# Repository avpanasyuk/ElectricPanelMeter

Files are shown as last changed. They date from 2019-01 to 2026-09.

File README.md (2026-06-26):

# ElectricPanelMeter

A whole-panel electric power meter: custom measurement hardware plus ESP8266
firmware that reports voltage / current / power over the LAN and logs it, with
MATLAB and Python tooling for readout and analysis.

## Layout

- **Hardware** — `Altium/` (PCB), `CAD/`, `Drawings/`, `LTspace/` (LTspice
  schematics) for the measurement boards.
- **`FirmwareV2/`** — current [PlatformIO](https://platformio.org) ESP8266
  firmware (`board = nodemcu`, 4 MB flash, LittleFS). One source builds two
  variants for the main and sub units:
  - `pio run -e main` → device `EPM_main` (`-DVERSION=1`)
  - `pio run -e sub`  → device `EPM_sub`  (`-DVERSION=2`)
  It vendors the shared `C_General` / `C_ESP` / `C_ARDUINO` submodules and uses
  `avp::StaticWebServer` (web UI / config / OTA) plus `avp::RemoteLog`, which
  POSTs `<filename>,<csv>` rows to the home server's `http_server.py` log sink.
  See `FirmwareV2/CLAUDE.md` for build and agent notes.
- **`Firmware/`** — the original (V1) firmware, kept for reference.
- **`MATLAB/`** — analysis code; vendors `github.com/avpanasyuk/MATLAB` at
  `MATLAB/AVP_LIB`. Logging is push-based: since firmware v4.00 the device POSTs
  its CSV rows straight to the home server's `http_server.py`, so no host-side
  polling script is needed.
- **`conf_*.m`, `*.csv`, `*.xls`** — configuration and recorded data.

## Building the firmware

```
cd FirmwareV2
pio run -e main        # main unit  (EPM_main)
pio run -e sub         # sub unit   (EPM_sub)
pio run -e <env> -t upload
```

The firmware libraries are git submodules — clone the repo with `--recursive`
(or run `git submodule update --init --recursive` after a plain clone).

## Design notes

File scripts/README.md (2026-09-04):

# scripts

Data-repair and maintenance drivers for the panel-meter logs on bsd. Run them there
(`python3`), or pipe them over ssh; they take absolute paths and touch nothing else.

⛔ **Every script here computes watts the way `read_file.m` does, and that changed on
2026-09-04**: the GND column is the additive offset common to all channels, so it is
subtracted SIGNED and the magnitude is taken last — never `max(|col| - |gnd|, 0)` per
row, which is the wrong sign on a reversed-CT channel (`Subpanel Red`, `Main Black`,
`26`) and understates it by `2*gnd`. Keep any new script consistent with `read_file.m`.
Slopes and shares are invariant under the change; levels are not.

| script | what it does |
|---|---|
| `diurnal_modulation.py` | Which main-unit channels carry real load, by MODULATION rather than level. A residual offset is constant, so it cannot make a diurnal shape: a channel's hour-of-day swing against the GND column's own separates load from offset below ~25 W, where the level says nothing. >~10x the reference = load. Recompute the yardstick per month. |
| `gnd_sign_correction.py` | How much every past main-board figure moves under the signed-GND fix, month by month, for a consumer that has to correct published numbers rather than re-derive them. Output is committed as `data/gnd_sign_correction_by_month.csv`. Reads the whole archive; ~10 min on bsd. |
| `merge_split_months.py` | Rebuilds one file per month for a `PowerMonitor.*.csv` that arrived split. Dry run by default, `--apply` to change anything. Concatenates in time order (the pieces do not overlap), refuses on a row-count mismatch or a non-increasing join boundary, and moves the sources to `/POOL/ARCHIVE/ESP_LOGS_PRE_MERGE/` rather than deleting them. |
| `channel_health.py` | Per-channel median / p95 / mean watts and duty for the main unit over one or more merged months (`python3 channel_health.py 02 04 08`), using `read_file.m`'s formula. For telling a dead CT from an off breaker: a breaker comes back across months, a fallen CT does not. |
| `gnd_daily.py` | Daily medians for every main-unit channel over the months given, plus each channel's hi/lo contrast and correlation against `Grounding strip`'s high days. Written to find which circuit switches with the intermittent ground current; the answer so far is none of the metered ones. |
| `port10_history.py` | Monthly medians for selected main-unit channels across every month in the archive, plus the raw covariance value beside the GND reference. Dates when a channel changed state, which is what separates a CT that came off from one that never read right. |
| `port9_divider.py` | Regresses port 9 (the GEC CT) on the service-neutral unbalance `|Main Red - Main Black|` per file. The SLOPE is the share of neutral current diverted onto the water main, and it is calibration-proof (numerator and denominator share the board coefficient), so it is comparable across firmware epochs. A rising share is the service-neutral degradation signal; a collapsed r means the CT has moved off the conductor. |
| `port9_paired.py` | The same share by BOTH estimators -- level regression and paired differences of 1-minute means. Prefer the difference slope. Two channels that both follow the daily household rhythm correlate through that common mode whether or not they are physically coupled, so the level regression is only trustworthy when the two agree; where they diverge, the coupling is weak and the level figure is the artefact. |

`merge_split_months.py` was written for the 2026-06/07/08 split, which came from
`http_server.py` rotating past 10 MiB into a single `.1` that it overwrote. That is
fixed at the sink — a filename carrying the month is now exempt from rotation — so this
should not be needed again. Kept because it records exactly how those three months were
reconstructed, and because it is the tool if a month ever splits again: edit `NAMES`.

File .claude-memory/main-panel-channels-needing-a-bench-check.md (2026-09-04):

---
name: main-panel-channels-needing-a-bench-check
description: "Port 9 is the x570 branch circuit (earth path before 2024-10), not the grounding strip; the GEC question is closed as topology; channel labels here are hypotheses, and a level under ~25 W is offset while its modulation is still real"
metadata:
  node_type: memory
  type: project
---

Measured 2026-09-04 with `scripts/channel_health.py` and `scripts/gnd_daily.py`
(main unit, `read_file.m`'s formula).

## Port 9 — the x570 branch circuit, and the GEC question it used to be

`conf_main_v0.m` labels port 9 `x570 branch (earth path before 2024-10)`. The label is
era-explicit because the conf is applied retroactively to all v0 main data and the CT has
been on more than one thing.

### What it is now

The branch circuit feeding the **x570 workstation**, on the **black leg**. Proven twice:
HOUSE_POWER caught x570's smart plug stepping 78 → 811 W and got
`port9 = 1.037 × plug_raw + 4.2 W`, residual sd 40 W, edge simultaneous to the minute —
the ~4 W intercept says that circuit carries x570 and essentially nothing else. Confirmed
here with no plug in the chain: over 2026-08/09 the 350 minutes where port 9 steps >3σ
land in `Main Black` alone (`Main Red` 0.032, `Subpanel Black` 0.007, `Subpanel Red`
0.031, `26` 0.000; r = 0.91 on black). **A CT on an earth path cannot do that** — it
appears as a fraction of the neutral *unbalance*, never 1:1 into one leg.

### Which era is which — the shape test

Correlation of the 1-minute difference in port 9 with each feeder, over **all** minutes,
no selection. ⛔ Slopes are useless inside this span: port 9 sits in the ground-subtraction
residual for most of it, so its steps are near-noise and slope estimates blow up past 100.
Correlation is scale-free and survives that. ⚠ `sub_r` and `sub_b` mirror `red` and
`black` exactly, an artefact of signing each channel by its own long-run mean — compare
r_red against r_black as magnitudes.

⛔ **First check whether the channel is the reference.** `r(Δp9, Δgnd)` in raw signed
counts — no sign convention involved — is ≈0 for every month 2018-12…2024-09, then
**0.890, 0.931, and 0.984–0.996 for 2024-10 through 2025-06**. In that window port 9 *is*
the GND column: the CT reads nothing, `p9 − gnd` is ~0, and any statistic built on it
correlates with every channel through the shared `gnd` term rather than through load.
It carries signal again from 2025-12 (r back to −0.25…−0.65).

| era | raw p9−gnd median | r(Δp9,Δgnd) | r_red | r_black | reading |
|---|---|---|---|---|---|
| 2019-06/07 | −1124 | 0.00 | 0.720 | 0.242 | earth path |
| 2022-06/07 | −866 | 0.01 | 0.807 | 0.359 | earth path |
| 2024-03/04 | −4412 | 0.02 | 0.505 | 0.496 | earth path |
| 2024-08/09 | **+8068** | 0.06 | 0.296 | 0.107 | earth path |
| 2024-10/11 | −60 | **0.89–0.93** | 0.211 | 0.694 | ⛔ no signal — inadmissible |
| 2024-12…2025-06 | ~+150 | **0.98–0.996** | — | — | ⛔ no signal — inadmissible |
| 2026-02/03 | +252 | −0.27 | 0.075 | 0.239 | one leg |
| 2026-08/09 | +1370 | −0.04 | 0.012 | 0.277 | one leg |

⚠ **The `r_black` = 0.694 at 2024-10/11 is that artefact, not a branch signature** —
"black high, red low" is the default for any channel sitting at the reference, because
`Main Black`'s CT is reversed so its watts carry `+gnd` just as a below-reference port 9
does, while red-signed channels carry `−gnd`. HOUSE_POWER caught this; its cleaner
statistic is `asym = pr_black + pr_sblack` (gnd-partialled), which cancels common mode
because those two reversed CTs mirror each other exactly, and which puts 2024-10/11 at
+0.002 — indistinguishable from 44 months of earth path.

**Two CT events. The first is dated; the second is bounded, not dated:**

1. **June–July 2024**, his panel work (240 V garage circuit, another outlet, "maybe moved
   ground wire CT"): the raw sign flips −4412 → +8068 and the magnitude nearly doubles,
   but the shape stays earth-path. **Reversed or repositioned on the earth path**, not
   moved to a load. The coupling changed, which is why the diverted share is only
   consistent up to 2024-04.
2. **The move onto the branch: bounded to 2024-10 … 2025-12, best guess 2024-10.** What
   is certain is a real discontinuity at 2024-09 → 2024-10 — the raw count collapses from
   +7664 to −60 — which needs a physical cause, and no other discontinuity falls between
   there and the channel carrying signal again in 2025-12. That is parsimony, not
   measurement: from 2024-10 to 2025-06 port 9 is the reference and reads nothing, the
   board is dark 2025-07…2025-11, and **a branch circuit with nothing running is
   indistinguishable from a CT clipped to nothing at all**. HOUSE_POWER's `asym` first
   shows the one-leg signature in 2026-01, but that dates the first observed LOAD, not the
   CT move, so it excludes nothing earlier. ⚠ No data gap and no repo trace at 2024-09/10
   — the board was not powered down, so this move left none of the tells the first one
   did. What he did in the panel that autumn is the one open question on this channel.

⛔ **2026-08 is not a CT event** — do not read it as a re-seat or an onset. It is x570
starting to run: `asym` quadruples there while the channel had already been showing a
steady one-leg asymmetry since 2026-01. ⚠ The identity as x570 specifically is anchored
only at the 2026-08/09 end.

⭐ **Corroboration for the modulation rule from a second direction**: through 2026-01…04
the channel sits at 240–322 counts (12–17 W), squarely "pure residual" by level — yet its
`asym` holds a consistent −0.07. Something small and real was on that circuit months
before x570 came back. The ~25 W threshold governs the LEVEL only; the modulation carries
usable signature well below it, exactly as the hour-of-day swing test says.

### Gain

**Port 9 reads ~1.07 × Main Black, bracket [0.97, 1.18]** — ~1.08 absolute against the
feeders' ~1.01. HOUSE_POWER's plug-derived ×1.12 sits inside it; so does 1.00, so
**per-port gains differing by ~10 % on one board is supported, not established**. The
width is this method's, not theirs: their number is a difference of means across a
controlled 733 W step (±3 %), and its uncertainty lives in the plug's unchecked current
leg.

⛔ **Quote the bracket, never a point.** Selecting minutes on |Δport9| inflates its
variance with its own noise and attenuates the forward slope to 0.846 — which reads as
"port 9 is low" and is an artefact. Selecting on |Δblack| instead picks mostly other loads
on that leg (r = 0.107). Use `[slope(y|x), 1/slope(x|y)]`, both from the port-9-selected
set.

### The GEC finding — CLOSED, do not reopen

⛔ **Do not ask him to move the CT back.** He decided on 2026-09-04 that it stays and that
no alarm is built on the diverted share. The conductor port 9 used to watch is the panel's
**grounding electrode conductor to the water main**, clamp-measured at **3.2–3.3 A**:
parallel-path objectionable current (NEC 250.6), because the metal water service is a
bonded electrode and the utility neutral is multi-grounded, so neutral return divides
between the service neutral and the water main. A copper water main is not much worse a
conductor than an aluminium service neutral, and the divider ratio implies
`Z_gec ≈ 2.7 × Z_neutral`. It is topology, which is why nothing ever tripped on it in six
years — and the parallel path *lowers* effective neutral impedance (`Z_eff = 0.73 × Z_n`)
rather than raising it, so there is no degradation signal being lost.

⛔ **Never open the GEC/water bond while it carries current** — arcing, loss of the ground
reference, and if the utility neutral is compromised the pipe may carry the
neighbourhood's return, so breaking it can energise the plumbing. A "remove the bond
jumper" test applies to a *load-side* bond only, never here. The one safe decisive test if
it is ever reopened: open the main disconnect and re-clamp the GEC — gone means his own
load (look for a load-side N-G bond, 250.142(B)); still there means utility/neighbour
return, and a POCO matter.

**The diverted share** — port 9 regressed on the service-neutral unbalance
`|Main Red − Main Black|`, `scripts/port9_divider.py` — was flat at **0.285–0.298 across
2019–2023**, and the series ends at **2024-04**. ⚠ One residual, recorded and not pursued:
it rose to 0.326 [0.322, 0.330] in 2024-03 and 0.329 [0.326, 0.332] in 2024-04 —
non-overlapping CIs — *before* the panel work, so his answer does not account for it.

⛔ **Use the PAIRED-DIFFERENCE slope, never the level regression** (`port9_paired.py`).
Port 9 and the unbalance both follow the daily household rhythm, so they correlate through
that common mode whether or not they are physically coupled — the level estimator read
0.43 where the truth was 0.045. The two agree to a few percent when a CT is on the
conductor and diverge 6–10× when it is not, and that divergence is itself the diagnostic:

| month | level slope | diff slope |
|---|---|---|
| 2022-06 | 0.315 | 0.319 |
| 2024-04 | 0.350 | 0.336 |
| 2024-08 | 0.064 | 0.063 |
| 2026-01 | 0.001 | −0.001 |
| 2026-08 | 0.204 | 0.034 |
| 2026-09 | 0.431 | 0.045 |

### Instrument facts established while chasing this

- **Crosstalk and a load-dependent GND reference are both ruled out.** Against 106
  compressor steps >50 W the feeders respond at slope 0.31–0.35 as they must, while port 9
  gives 0.0037 (r = 0.023); and 1834 feeder steps >200 W move the GND reference at slope
  −0.005 (r = −0.078). Low-power channels carry no load-scaling floor.
- ⚠ **Citation hygiene.** NEC **250.6** (*Objectionable Current*) and **250.142(B)**
  (*Load-Side Equipment*) were confirmed independently. The IAEI "parallel paths" article
  does not resolve here, so its "large percentage of the neutral current" quote is
  **unverified**; NEC section *text* was only ever seen via a third-party scrape of
  NFPA-copyright material, which is no authority. Verified sources: Mike Holt's N-G
  voltage article, EC&M's "What's Wrong Here" (green bonding screw in a load-side
  subpanel).
- ⭐ **One minute with a clamp meter beat eight years of logs**, and one question to him
  then dated the CT move. The archive cannot separate a real current from a mislabelled
  CT. Reach for the instrument and for the owner before the regression.

**HOUSE_POWER owns the electrical question; this project owns the meter.**

## ⛔ "Exactly 0.0 W" means FLOORED, not disconnected — in any figure predating 2026-09-04

`read_file.m` used to compute `max(|col| - |gnd|, 0)`, so any channel whose raw value
sat below the GND reference reported a flat zero. In 2024-10 **four** main channels read
0.0 every day — A/C compressor, Grounding strip, 28 Air handler, 40 Lida — and the
A/C one is simply "October, no cooling". A zero therefore means *below the noise
reference*, and only a **step in the raw value against a stable reference** says
something physically changed. Read the raw columns before calling a channel dead.

The clamp is **gone** as of the signed-subtraction fix, so such a channel no longer reads
0.0 — it reads the magnitude of its residual against GND, which is an artefact of order
±20 W and not power. Same rule, different symptom: read the raw columns.
See [[read-file-ground-subtraction-sign]].

## ⛔ `conf_main_v0.m` channel LABELS are not reliable

Port 10 is labelled `28 Air handler attic`. The attic air handler runs
continuously and a blower is hundreds of watts, but the channel read **3–20 W from
2018-12 to 2024-09** and then **exactly 0.0 from 2024-10 on** (raw stepped ~360 →
201 against a ~308 GND reference; it now sits below the reference, which floored the
watts at zero under the old estimator). ⭐ **It is dead, confirmed by modulation**: its
hour-of-day swing is 1.3× the GND column's own, i.e. it tracks the reference and carries
no load at all. That also rules out reading its +6.7 W since 2025-12 as an A/C response.

His reading: **3–20 W is far too low for that air handler, so the channel is probably
mislabelled** — it was measuring some other small load, which stopped in 2024-10.

**Consequence: treat every label in `conf_main_v0.m` as a hypothesis, not a fact.** That
is no longer speculative — port 9 spent six years labelled `Grounding strip` while the CT
moved twice, and the label cost this project a long grounding-electrode investigation
before a clamp meter settled it.

Open questions for a panel visit: what port 10's CT is actually clamped on, why it
went dead in 2024-10, and whether the attic air handler is metered at all.

## ⛔ `38 Vova` (port 11) — NOT disturbed by the 2024 work. It swings on its own.

Two sessions asserted a 2024 collapse here and both were wrong, because both read one
high run as a baseline. The full corrected series (monthly means, W, whole archive)
settles it:

| span | port 11 |
|---|---|
| 2018-12 … 2019-08 | 8.5–13.7 |
| 2019-09 … 2020-05 | 18.9 → 34.4, rising |
| 2020-06 … 2021-07 | 36.4–**107.4** |
| 2021-08 | **7.7** — the sharpest step this channel has ever made |
| 2021-10 … 2023-11 | 12–47, variable |
| 2023-12 … 2024-05 | 45.8–64.9 |
| 2024-08 … 2026-01 | 2.0–12.6, except **34.7** in 2025-04 |
| 2026-02, -03, -06 | **38.9, 48.0, 28.2** |

⇒ **There is no discontinuity at the June–July 2024 panel work.** The channel's monthly
mean has ranged 2–107 W for its whole life and returns to 28–48 W repeatedly after 2024.
Its one genuinely sharp, unexplained step is **2021-07 → 2021-08, 107.4 → 7.7 W** — which
nobody has looked at, and which is far larger than anything in 2024.

⚠ **Its low months are not level measurements.** 2–12 W sits inside the ±20 W
per-channel residual, so "port 11 was quiet" and "port 11 read nothing distinguishable
from zero" are the same statement about its LEVEL. The same trap makes channel `24`
appear to step 12 → 26 W at the 2025-12 flash: 270 counts against the GND column's own
250-count step, i.e. the reference, not the circuit — the feeders moved only ×1.105 there.
**Test the modulation instead**: `24` swings 17× the GND column's own diurnal swing and
port 11 19×, so both carry real load regardless of where their levels sit. The rule and
the measured yardstick are in [[read-file-ground-subtraction-sign]].

⇒ The June–July 2024 work disturbed **port 9 only**. `24` and `26` are flat across it
(12 W, and 111–186 W either side), and so, correctly read, is port 11.

## `40 Lida` (port 12) — alive, and the one channel that matches its label

⛔ **The "exactly 0.0 from 2021-10 onward" that this note used to carry was the old
estimator's clamp, not the circuit.** Corrected, port 12 reads a small but unmistakably
real load: 2026-02 mean 11.8 W, median 10.5, p95 24.1. Its level sits inside the ±20 W
residual, so the level alone says nothing — but its **hour-of-day swing is 615.6 counts,
43× the GND column's own**, the largest ratio on the board, running 11.5 → 43.5 W with a
midday peak. That is a daily-use circuit behaving exactly as its door-table label implies,
and it is one of the few main-panel channels that does.

Its level did drop around 2021-09 (15–91 W before), which is real and unexplained, but the
channel was never dead. **Not a fault.**

## ⛔ There is NO constant reference load — do not use `22 heat exchanger`

`22 heat exchanger` looks like the steadiest load in the house (within 2026-02:
p05 109, p95 123 W) and its monthly median moves 122 W (2019-01) → 79 W (2025-05)
→ 119 W (2025-12) → 107 W (2026-08). **That is not instrument drift.** The user
ran it through an **auto-transformer and adjusted it from time to time**, removing
the auto-transformer during 2026. Its level is a record of those adjustments, so it
cannot calibrate anything and a year-over-year change in it is not a finding.

What does stand: the **GND reference channel steps ~300 → ~550** at the 2025-12
firmware rebuild (the `/read` fix; the sampling loop was reworked again in
2026-05). That channel is a grounded mux input, so it carries the additive offset
common to every channel, not a load — and since it is *subtracted* from every
channel, a step in it moves every reading. Not evidence of a gain change, but it is
**epoch-dependent bias**, and it scales the old code's wrong-sign subtraction on a
reversed-CT channel as `2·gnd`: ~85 W per reversed channel before the step, ~140 W
after. `Main Black` is reversed, so pre-fix mains totals are low by that much and the
error nearly doubles across the 2025-12 boundary.
See [[read-file-ground-subtraction-sign]].

**No validated constant load exists in this data**, so gain stability across
firmware epochs is currently unmeasured in either direction. A known resistive load
would settle it, and is the same bench test that settles the two-board question.

## Reading the numbers

Never quote a `max` from this data — at 0.33 % duty an extremum is an aliasing
artefact. Resample on **local** time: a UTC monthly resample relabelled to local
shifts every bucket by a month.

**Feeder arithmetic closes on the main unit, and closes better since the signed-GND fix.**
2026-02 means: Main Red + Black **2401.2 W**, Subpanel Red + Black **2071.5 W**,
difference **329.7 W** against **368.6 W** of metered main branches — of which ~18.6 W is
port 10's pure residual, so ~350 W is real. That is a ~6 % closure, against a 15 % gap
under the old estimator. ⚠ The *difference* is invariant under the fix (each leg pair
contains exactly one reversed CT, so both sides gain the same ~140 W); it is the branch
total that moved.

So the ~40 % gap between the subpanel feed and the sub unit's 14 branches is a sub-side
question — unmetered subpanel circuits, or the two boards' separate calibrations
(`conf.coeff` 385 vs 328.2). A known resistive load read on both units separates them, and
is immune to the PLUG fleet's undocumented 1.08 power trim.

See [[epm-main-unreliable-for-years]].

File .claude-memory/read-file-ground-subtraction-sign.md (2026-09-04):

---
name: read-file-ground-subtraction-sign
description: "read_file.m subtracted the GND reference from the MAGNITUDE, understating every reversed-CT channel (incl. Main Black) by ~140 W; fixed. There is NO 2 kW rectification floor - that was solar."
metadata:
  node_type: memory
  type: project
---

**Retracted: there is no ~2.1 kW rectified floor on the feeders.** The constant
`Main Red + Main Black` that looked like one is **gross consumption** — the PV array is
line-side tapped, so the main-panel CTs sit downstream of it and never see the
production, while the bill reads net. HOUSE_POWER owns that identity
(`gross = net + production`) and the resulting per-epoch gains.

**What is really wrong with the old `read_file.m`, in order of size.** Each CSV value is
`cov(V,I)` over one free-running 60 Hz window (`harvest_scan()` in `main_v2.cpp`), so it
is **signed**; the sign is CT orientation, not direction of flow. The last column is a
grounded mux input — no CT, so it carries only the additive offset every channel picks
up (~505 counts on the main board, Sept 2026).

1. **Wrong-sign ground subtraction — the real defect.** The old code did
   `max(|col| − |gnd|, 0)`. For a channel whose CT is reversed (`Subpanel Red`,
   **`Main Black`**, `26`) that subtracts the offset from the magnitude instead of from
   the signed value, understating it by **2 × gnd ≈ 1012 counts ≈ 140 W**. `Main Black`
   is a feeder, so the mains total was low by ~140 W — **+5.6 % on Sept 2026**
   (2533 → 2675 W).
2. **Rectification of near-zero channels — real but small.** `mean(|x|) ≠ |mean(x)|`
   still holds, but consecutive-sample scatter is only ~85 counts on Main Red and
   ~225 on Main Black = **10–30 W**, nowhere near the ~1000 counts a 2 kW floor needs.
   It only bites a channel sitting at the offset, and there the `max(…,0)` clamp
   dominates anyway.

**Measured across the whole archive** (`scripts/gnd_sign_correction.py` →
`data/gnd_sign_correction_by_month.csv`, 79 months, 2018-12…2026-09): the mains
correction is **+3.2 to +5.0 % in every month through 2025-06**, then **+4.7 to +7.2 %
from 2025-12 on** — the GND channel's ~300 → ~550 count step at that firmware rebuild,
showing up exactly where it must. In watts, ~82 W before and ~150 W after. It is a
per-epoch multiplicative-looking bias that is really a fixed additive one, so it hits a
low-consumption month hardest.

**The GND column is a common additive offset — verified, not assumed.** With its breaker
off, `25 - Main A/C compressor` sits at a median of **517 counts** against the GND
column's own **511**. A switched-off load reading exactly the reference is what makes the
signed subtraction correct.

**Residual floor after the fix: ±20 W per channel, not zero.** `28 Air handler attic` and
`40 Lida` average *below* GND (363 and 191 counts vs 505), so the offset is not identical
across mux inputs, and a level of that size is not by itself a measurement.

⛔ **But test the MODULATION, not the level — a residual is constant, so it cannot make a
diurnal shape.** "Under 25 W means nothing" is too blunt and throws away real load. The
GND column's own hour-of-day swing is the yardstick: **14.2 counts** over 2026-03
(357950 rows). Against it, same month:

| channel | swing | × GND | W range |
|---|---|---|---|
| `40 Lida` | 615.6 | **43×** | 11.5 → 43.5 |
| `38 Vova` | 273.9 | **19×** | 43.4 → 57.6 |
| `24` | 238.7 | **17×** | 13.0 → 25.4 |
| port 9 (x570 branch) | 80.6 | 5.7× | 9.9 → 14.1 |
| `28 Air handler attic` | 18.8 | **1.3×** | −18.9 → −17.0 |

⇒ `40 Lida` and `24` carry real diurnal load of tens of watts even though their LEVELS sit
in the residual band. ⇒ `28 Air handler attic` tracks the reference and does not modulate
at all — which confirms it reads nothing far more strongly than the level argument did,
and rules out the "responds slightly to A/C" reading of its +6.7 W since 2025-12.

**The rule: below ~25 W a branch channel's LEVEL is offset; its MODULATION is real when it
is ≳10× the GND column's own swing in the same month.** Compute the yardstick per month —
it scales with the offset, which stepped at the 2025-12 flash.

⛔ **Before any correlation or shape statistic on a low channel, check `r(Δchannel, Δgnd)`
in RAW SIGNED COUNTS.** A channel whose CT reads nothing does not go quiet — it becomes
the GND column, and then every statistic derived from `channel − gnd` correlates with
every other channel through the shared `gnd` term, with no load anywhere. It looks exactly
like a real coupling. Port 9 hits 0.89–0.996 across 2024-10…2025-06 and manufactured a
convincing "black leg" signature there; ≈0 is the healthy value, and every month
2018-12…2024-09 sits at ≈0. **A high r means the channel is inadmissible, not that it is
coupled to something.** Since a reversed CT's watts carry `+gnd` and a normal one's carry
`−gnd`, the artefact always looks like "the reversed channels respond and the others
anti-respond" — cancel it with a sum over a mirrored pair
(`asym = pr_black + pr_sblack`, gnd-partialled) rather than reading the halves.

**How to apply:** `read_file.m` now subtracts GND signed, applies one fixed per-channel
sign taken from the whole-record mean, and no longer clamps at zero — so reverse flow
survives (a future load-side PV, battery or bidirectional EV charger would be visible;
the present line-side array still is not). Any watt figure published before 2026-09-04
for a reversed-CT channel is ~140 W low. See
[[main-panel-channels-needing-a-bench-check]].

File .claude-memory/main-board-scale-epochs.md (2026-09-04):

---
name: main-board-scale-epochs
description: "Complete record of every date the reported watt scale could have moved - conf edits, firmware, hardware - plus the GND column as the epoch instrument. A conf edit can never make a boundary; the FLASH date does, not the commit."
metadata:
  node_type: memory
  type: project
---

Assembled 2026-09-04 from the repo's own history, for HOUSE_POWER's bill calibration,
which was inferring epochs from the signal. Use this instead of a detector.

⛔ **A `conf.coeff` or port-coefficient edit CANNOT create an epoch boundary.** The
conf is selected by the version digit in the log filename and applied retroactively to
every row read with it, so an edit uniformly rescales that version's whole history — it
never steps the data at the edit date. The only conf-driven boundary is a change of the
*filename version digit* (sub v0→v1→v2), which selects a different file.

⛔ **The commit date is not the boundary — the FLASH date is, per board.** Proof: the
sampling rewrite is 2025-07-03, but main's data steps at 2025-12, because main logged
nothing between 2025-06 and 2025-12 and was reflashed around 2025-12-10. The two boards
do not share boundaries. Bound a flash by the coverage gap.

## Conf edits — complete

- `conf_main_v0.m`: `conf.coeff = 385` never changed since the file was created
  (351866c, 2019-05-11). Port coefficients changed **once**: 2020-01-02 (34e18ec), ports
  6 and 10 `50` → `50/2` "two phases" — a retroactive ×0.5 on `25 - Main A/C compressor`
  and `28 Air handler attic`. 2024-08-13 (5538c31) is **labels only**. The four feeder
  coefficients (18.8) have never moved.
- `conf_sub_v2.m`: `conf.coeff` 376.62 → 328.18 at 2025-07-02 (065f33d) — retroactive
  ×1.148 on all sub-v2 watts. 2026-09-02/03 changed `conf.dir` only.
- `conf_sub_v0.m` / `conf_sub_v1.m`: 376.62, untouched since 2019-05-11.

## Firmware — only three things can move the scale

`LastPower = (Power − Current·Voltage/N)/N` normalizes by sample count, so the sampling
RATE does not change the scale. Only an explicit factor, the mux settling `Delay`, and
the V→I sample phase can.

- `SAMPLES_IN_WF = 600` unchanged since 2018-12-05; `Delay = GetDelay(4)` (160 µs)
  unchanged since 2018-12-09 (`GetDelay(5)` for the four days before).
- **2019-05-10 → 05-11** (a87409d → 1d09284): phase interpolation added, reverted next day.
- **2025-07-02 → 07-03** (065f33d → eda9b90): `NumSamplesPerWL = 8` put an explicit extra
  `/8` on every reported power. Anything logged in that one-day window is **8× low**.
- ⭐ **2025-07-03 (eda9b90)**: rewrote the cadence to `WIFI_timeRatio = 10` — read one
  port flat out, then yield 10 wavelengths to WiFi. Changes the V→I sample spacing, hence
  the phase error, hence the gain. **This is the 2025/2026 boundary**, reaching main only
  at its 2025-12-10 flash.
- **2026-06-08 (c00840b, v5.04)**: fixed a race where `/read` and the bsd push stole each
  other's accumulator, so a value could be a partial scan. **Exclude 2026-05-25…06-08.**
- Everything else 2025-11 → 2026-06 is WiFi/OTA/mDNS/logging/LED, not the ADC path.
- **Nothing between 2024-08-13 and 2025-07-02** — one commit in that whole window, and it
  is the label-only conf edit.

## ⭐ The epoch instrument: the main board's GND column

The last CSV column is a grounded mux input, so it is the additive offset with **no load
in it**. Annual mean ADC counts from `data/gnd_sign_correction_by_month.csv`
(`gnd_counts`): 2019 297.8, 2020 298.4, 2021 295.0, 2022 305.0, 2023 309.0, 2024 306.0,
2025-12 562.8, 2026 528.0. Flat inside ±5 % for seven years, then one clean step, no
drift. **Two epochs on main and nothing else.** It is a board diagnostic, so it is the
check, not the key — but it beats any load channel. See
[[read-file-ground-subtraction-sign]] for why that column matters twice over.

## The 2024-06/07 gap — ANSWERED by him, 2026-09-04

He did the panel work himself: **added a 240 V circuit to the garage, added another
power outlet, and "maybe moved ground wire CT"** — his words, "it should not have
changed anything else." Main is dark through 2024-06/07 because he powered the board
down to work.

That accounts for the GND step (294.8 → 329.3 → 308.2 by 2024-10) and for port 9's CT
being reversed or repositioned on the earth path — the archive could never have supplied
either. ⚠ It does **not** account for port 9 becoming a branch channel: that is a second,
undocumented CT move at 2024-09/10, with no data gap and no repo trace
([[main-panel-channels-needing-a-bench-check]] has the shape test that dates it). **The feeders did not move**:
HOUSE_POWER's bill-plus-PV chain reads ~0.914 either side, so the board's scale is
unchanged. CT and wiring work, not calibration. Treat **2024-06-01 … 2024-08-01 as a
hard discontinuity for port 9 alone** — port 11 was wrongly added to it by both sessions
and does not belong (see [[main-panel-channels-needing-a-bench-check]]).

⛔ **The lesson, worth more than the answer: when a step lands in a window where the
meter also went dark, ASK HIM FIRST.** Those two coincide precisely because he powers the
board down to work on the panel, so the gap is the tell. Two sessions spent a long
exchange inferring a physical event from ADC counts, firmware history and commit logs,
and one question settled it. HOUSE_POWER records the same lesson in its own
`panel-work-june-july-2024.md`.

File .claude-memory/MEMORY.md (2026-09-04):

- [Power log data flow](power-log-data-flow.md) — every reader goes to `//bsd/ARCHIVE/ESP_LOGS`; `/mnt/T` still answers but is frozen at 2026-09-02.
- [ESP log sink rotation truncates months](esp-log-sink-rotation-truncates-months.md) — the 10 MiB rotation overwrote its single `.1` and destroyed most of Jun–Aug 2026; months since rebuilt to one file each; fix deployed on bsd.
- [EPM_main unreliable for years](epm-main-unreliable-for-years.md) — 9–63 % coverage since 2020, and 4.5 months of payload-free rows in 2025 that every liveness check read as green.
- [Main-panel channels needing a bench check](main-panel-channels-needing-a-bench-check.md) — port 9 is x570's branch circuit, not the grounding strip; the GEC's 3.2-3.3 A is closed as topology; labels in `conf_main_v0.m` are hypotheses, and below ~25 W the level is offset while the modulation is still real.
- [read_file ground-subtraction sign](read-file-ground-subtraction-sign.md) — no 2 kW floor (that was line-side solar); the real defect was subtracting GND from the magnitude, ~140 W low on every reversed-CT channel including Main Black. Fixed.
- [Main-board scale epochs](main-board-scale-epochs.md) — every date the watt scale could have moved; a conf edit never makes a boundary, the flash date does, and the GND column is the instrument.

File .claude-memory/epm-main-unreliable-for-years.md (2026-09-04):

---
name: epm-main-unreliable-for-years
description: "EPM_main has logged only 9-63% of wall-clock minutes every year since 2020, including a 4.5-month run of payload-free rows in 2025"
metadata:
  node_type: memory
  type: project
---

Coverage (% of wall-clock minutes actually logged), measured 2026-09-04 by the
HOUSE_POWER session across all 173 sink files:

| year | main | sub | | year | main | sub |
|---|---|---|---|---|---|---|
| 2020 | 62 | 86 | | 2024 | 40 | 80 |
| 2021 | 36 | 59 | | 2025 | **9** | 52 |
| 2022 | 42 | 47 | | 2026 | 59 | 53 |
| 2023 | 63 | 83 | | | | |

The only stretch in eight years where both units were near-complete is
2026-01 … 2026-04. 2026-05 onward reads low for both, but that is
[[esp-log-sink-rotation-truncates-months]], not the devices.

**2025-07-03 → 2025-11-15, EPM_main posted ~975,600 rows containing a timestamp
and one trailing comma — no payload**, at the normal 5 s cadence. It recovered
2025-12-10 15:22:23, mixed with short rows for ~24 minutes around that point.
**Diagnosed and long since fixed.** Commit `4787751` (2025-07-02, "a lot of time
is wasted on String reallocations") made `samples2string()` return a reference to
a static buffer that `/read` passed straight into `send()`; `5e500c6`
(2025-12-10 17:07, "was not formatting /read string properly") fixed it by
assembling into its own buffer. In 2025 the rows came from a host-side poller
reading `/read`, so a malformed response wrote a timestamp and an empty field.
Both boundaries bracket the commits with flash-then-commit ordering (data
recovered 2025-12-10 15:22, commit 17:07). Nothing to look for in current
firmware; treat 2025-07-03 → 2025-11-15 as a known-bad window and exclude it.

**Why it matters beyond the data:** the device was up, on WiFi, posting on
schedule; file mtime, growth rate and rows-per-day were all nominal for 4.5
months. Every liveness check reads green — only parsing the payload catches it.
Treat "posted but empty" as a distinct failure from "did not post".

**How to apply:** don't read a quiet stretch in the main-panel log as a house
event; check the unit first. Before trusting any long-run comparison of main
against sub, check coverage for that window — main's history is thin.

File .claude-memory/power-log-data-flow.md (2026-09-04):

---
name: power-log-data-flow
description: "Where EPM power CSV logs live on bsd, and which dir the MATLAB scripts read"
metadata: 
  node_type: memory
  type: project
  originSessionId: 8b29c43a-0137-4fb7-b923-2893ff129f92
---

The ESP firmware pushes power-meter CSV rows to bsd's `http_server.py` sink,
which writes them into **`/POOL/ARCHIVE/ESP_LOGS`**
(SMB share `//bsd/ARCHIVE/ESP_LOGS`). One directory, live and historical
together: there is no second location and no monthly move job. `MATLAB/show1.m`,
`show.m` and `month_by_month.m` all `cd` there, and `conf_sub_v2.m` sets
`conf.dir` to the same path.

**Why:** the old two-tier flow (live buffer on `/mnt/T` = `//bsd/USB_FLASH`,
month-end move to `/POOL/ARCHIVE/POWER`) was retired in the 2026-09-02 sink move.
`/POOL/ARCHIVE/POWER` no longer exists, and `/mnt/T` is still mounted but frozen
at 2026-09-02 21:11 — it answers reads with pre-move data and **no error**, so
anyone following the old note gets stale rows with no clue anything is wrong.

**How to apply:** every reader → `//bsd/ARCHIVE/ESP_LOGS`. Never `/mnt/T` or
`//bsd/USB_FLASH`. One file per month, no chunks — `ESP_LOGS_PRE_MERGE/` holds
duplicate rows and is deliberately outside the sink dir, so never glob the tree
recursively. Column 1 is dual-format (legacy Unix epoch +
`yyyy-MM-dd HH:mm:ss.SS` since 2026-06-23) and both can appear in one file,
handled by `read_file.m`.
See [[esp-log-sink-rotation-truncates-months]] before trusting a month's row count.

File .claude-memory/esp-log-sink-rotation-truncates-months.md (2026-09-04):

---
name: esp-log-sink-rotation-truncates-months
description: "The 10 MiB rotation that overwrote its single .1 destroyed most of Jun-Aug 2026; fixed in C_ESP and deployed, months rebuilt to one file each"
metadata:
  node_type: memory
  type: project
---

bsd's `http_server.py` rotated a log to `<file>.1` past 10 MiB and **replaced**
any existing `.1`. At the meters' ~104 KB/h it fired every ~4 days, so only the
last two chunks of a month survived. Roughly the 1st ~10:00 to the 23rd–26th of
2026-06, -07 and -08 is gone on both units — unrecoverable (written to `/mnt/T`,
UFS on a USB stick, outside every snapshot).

**Fixed in C_ESP `development` (9fc4625) and running on bsd.** A filename carrying
the month (`--no-rotate-pattern`, `MONTHLY_NAME_RE`) is exempt from size rotation,
so the power logs stay one file per month; other names keep the cap but the
over-size file is renamed to `<file>.<YYYYmmdd-HHMMSS>` and kept. Disk protection
is `--max-rows-per-min` plus a `--dir-quota-bytes` alert, neither of which deletes.
`test_http_server.py` sits beside it — run it after any change there.

Note for future pushes: `~panasyuk/GIT_REPS/LIBS/C/ESP` on bsd is a working clone
with `receive.denyCurrentBranch=updateInstead`, so **pushing C_ESP to `HOME`
updates the file the sink runs**. It takes effect only on the next `http_server`
restart, which drops in-flight POSTs and is the user's call.

**Repaired 2026-09-04:** 42,164 rows recovered from ZFS snapshots (the first
~10 h of each month, from the retired monthly rsync's copies), then each month
merged back to a single file — 115784/95224/98066 rows main, 96512/103779/92124
sub. Pre-merge sources kept at `/POOL/ARCHIVE/ESP_LOGS_PRE_MERGE/`, deliberately
**outside** `ESP_LOGS/` so a reader walking the tree cannot double-count them.
`scripts/merge_split_months.py` is the tool and the record of how.

**Why it stayed invisible:** the sink returned 200 and logged only
"Rotated <file>". Retention is no backstop either — POOL/ARCHIVE's weekly
snapshots have not fired since 2026-08-09, so a rotated chunk lived ~7 days in
the dailies and was then gone.

See [[power-log-data-flow]] and [[epm-main-unreliable-for-years]].

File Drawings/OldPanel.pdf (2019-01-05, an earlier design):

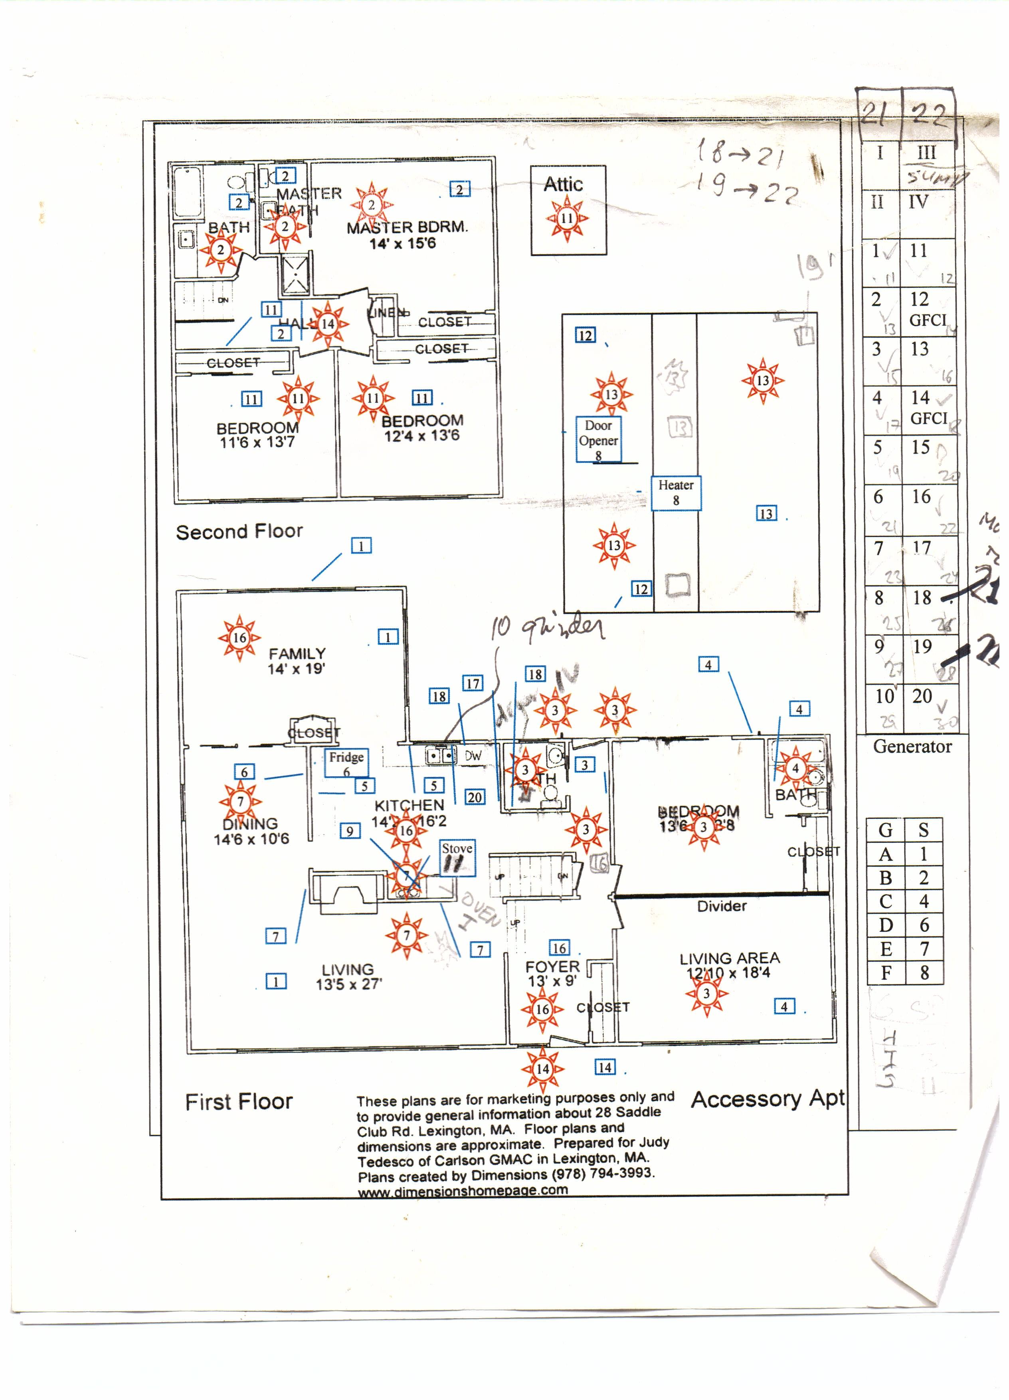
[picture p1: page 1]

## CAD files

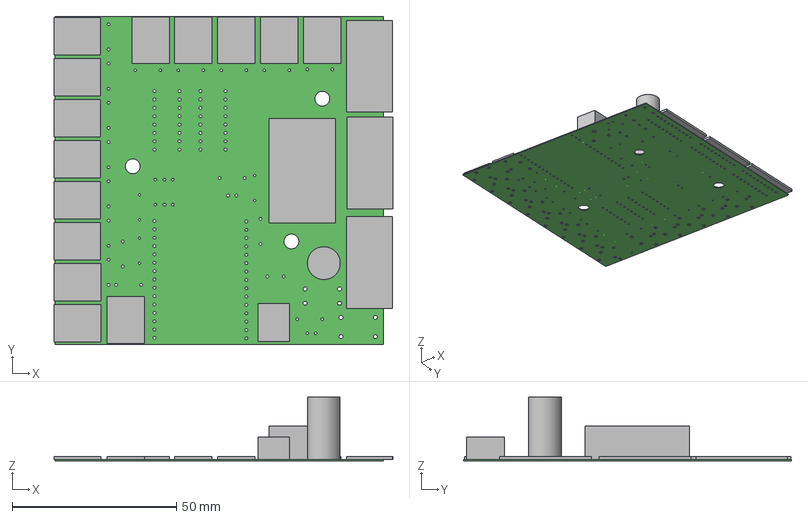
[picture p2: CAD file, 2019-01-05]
Altium/PCB1a.step
103.1 x 99.8 x 19.4 mm
Board
Extruded x 19

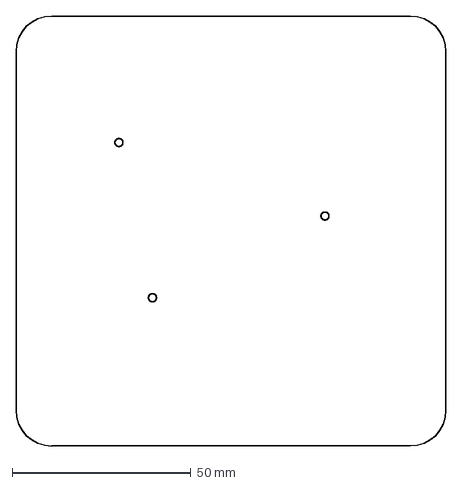
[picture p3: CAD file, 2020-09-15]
CAD/Part2.DXF
120.3 x 120.3 mm

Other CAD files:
CAD/Part1.STEP
Altium/PCB1a.DWG
Altium/PCB1a.DXF
CAD/Part1.DXF

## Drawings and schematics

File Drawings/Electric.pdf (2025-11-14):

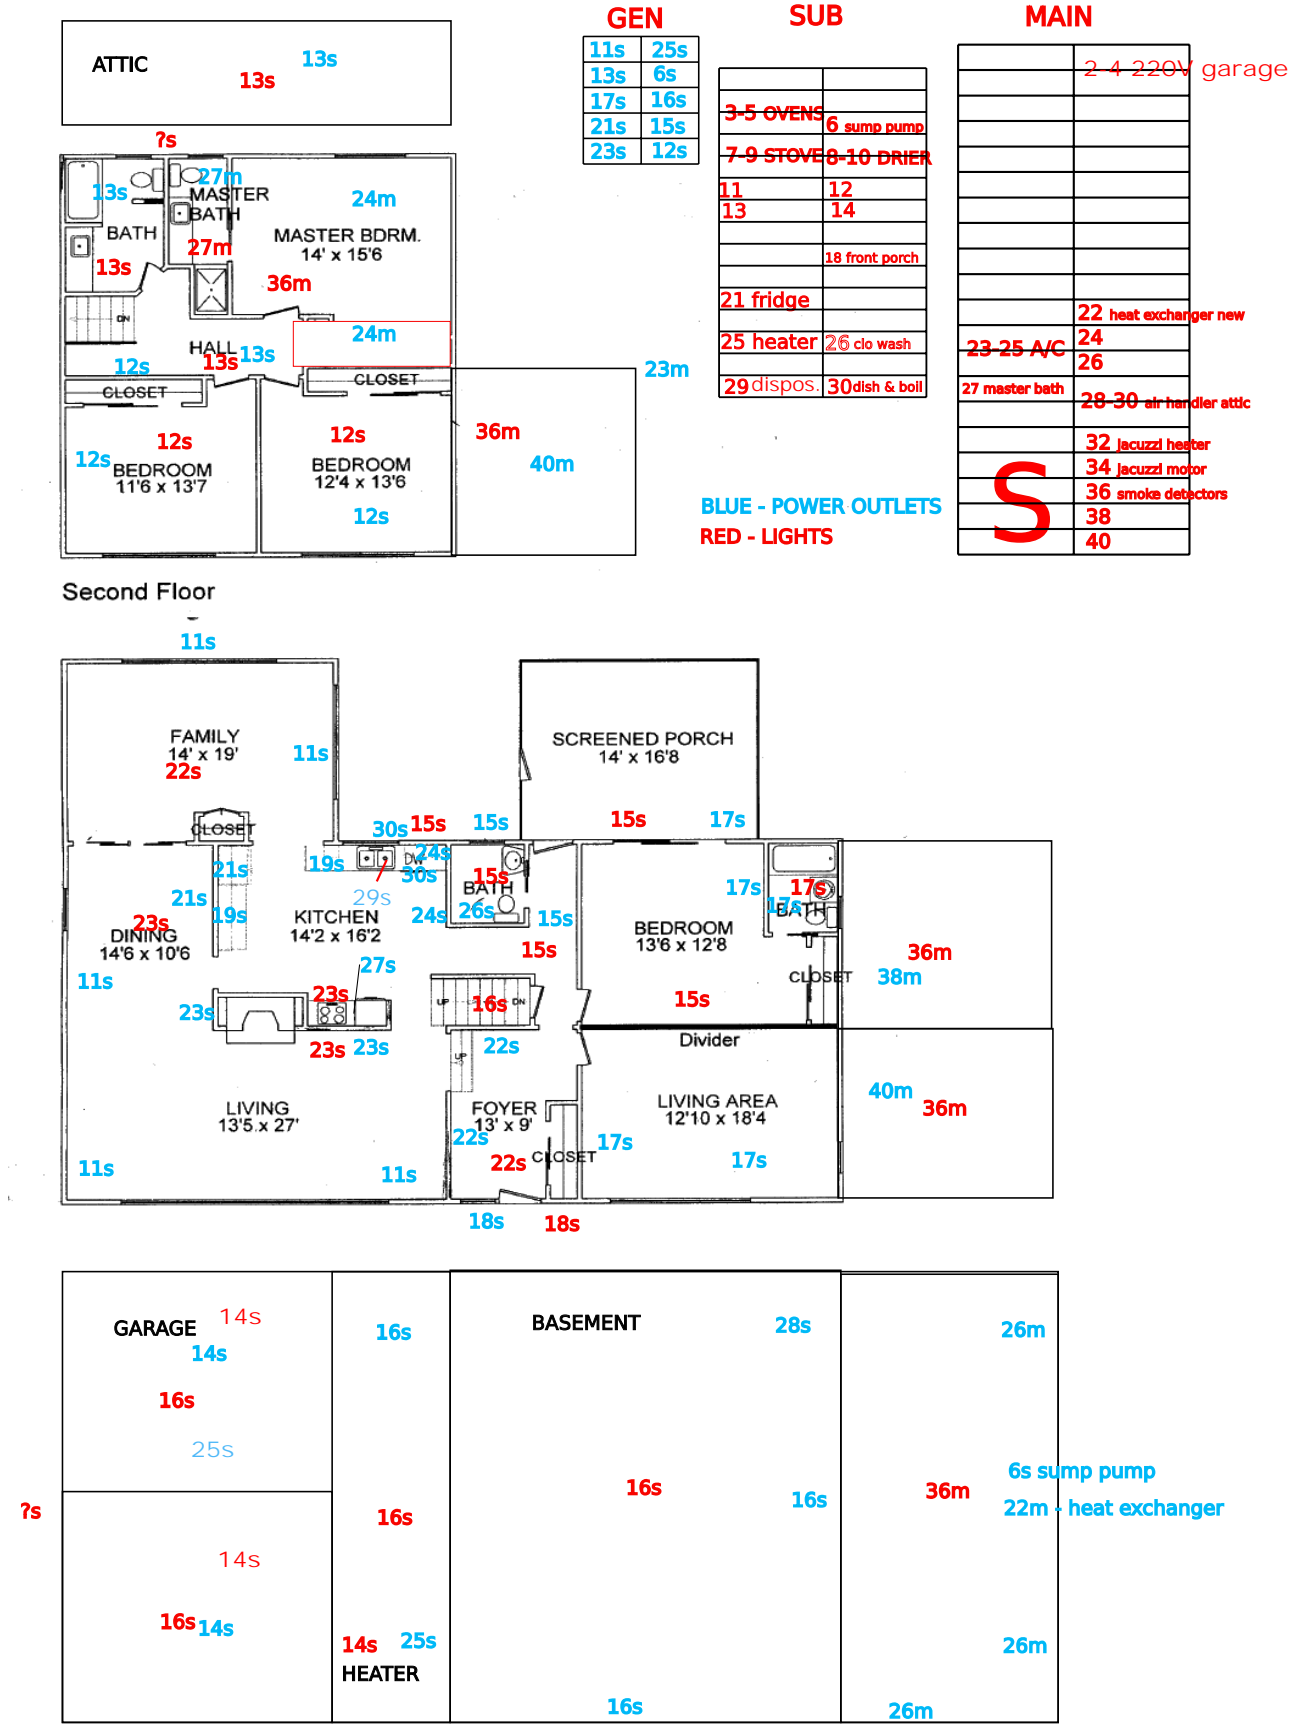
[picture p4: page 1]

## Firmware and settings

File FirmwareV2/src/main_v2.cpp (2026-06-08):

#include <stdint.h>
#include <stdio.h>
#include <time.h>
#include <Arduino.h>
#include <ESP8266WiFi.h>
#include <mDNSResolver.h>
#include "C_General/Macros.h"
#include "C_General/MyMath.hpp"
#include "C_General/MyTime.hpp"
#include "C_ESP/HTML_Log.hpp"
#include "C_ESP/StaticWebServer.hpp"
#include "C_ESP/fast_gpio.hpp"
#include "C_ESP/RemoteLog.hpp"

using WebSrv = avp::StaticWebServer; // 'Server' collides with ESP8266 core's global class Server
using BSDLog = avp::RemoteLog<>;     // POSTs <filename>,<csv> to bsd's http_server.py

#ifndef CONF_VERSION
#define CONF_VERSION 0 // configuration-version digit; overridden per-env in platformio.ini
#endif
#ifndef NTP_TZ
// US Eastern with DST. Change in platformio.ini build_flags if you're elsewhere.
#define NTP_TZ "EST5EDT,M3.2.0/2,M11.1.0/2"
#endif

#define DEBUG_SERIAL Serial

extern "C" {
  int debug_puts(const char *s) {
    avp::HTML_Log::Add(s, /*AddBreak=*/true); // <br> between log entries so /log is readable
#ifdef DEBUG
    if(DEBUG_SERIAL) {
      DEBUG_SERIAL.print(s);
      DEBUG_SERIAL.flush();
    }
#endif
    return 0;
  }
}

/////////////////////
// Pin Definitions //
/////////////////////
constexpr uint8_t LED_PIN = D8; // Thing's onboard, green LED
constexpr int ANALOG_PIN = A0;  // The only analog pin on the Thing
constexpr uint8_t NumCtrlLines_74HC4051 = 3;
constexpr uint8_t Num74HC4051 = 2;

static constexpr uint32_t GetDelay(uint8_t DelIndex) { // exponentially scaled delay
  return 10UL * pow(2, DelIndex);                      // us
} // GetDelay

// WF acronim is WaveForm, one 60 Hz period
static constexpr uint16_t SAMPLES_IN_WF = 600;
static constexpr uint32_t WF_SAMPLE_PERIOD = 1000000UL / SAMPLES_IN_WF; // microseconds

static uint32_t Delay = GetDelay(4); // tuned for no visible phase shift. Hmm, HOW?
static uint32_t NewSample = micros();
static inline void Set74HC4051_code(uint8_t c, uint8_t SwitchNum);

#if VERSION == 2
#include "V2.incl"
#else
#include "V1.incl"
#endif

constexpr uint8_t VoltagePortI = 0;
constexpr uint8_t GND_PortI = NUM_ports - 1;

static inline void Set74HC4051_code(uint8_t c, uint8_t SwitchNum) {
  for(uint8_t BitI = 0; BitI < NumCtrlLines_74HC4051; BitI++)
    digitalWrite(ControlLines[SwitchNum][BitI], (c >> BitI) & 1);
} // Set74HC4051_code

static inline bool is_past(uint32_t time_us) { return (micros() - time_us) < (1UL << 31); } // is_past

// integration data
static struct {
  float Power, Voltage, Current;
  uint32_t NumSamples;
} Integral[NUM_ports];

static uint32_t NumScans;

// Last complete per-port power, refreshed once per finished scan by harvest_scan().
// Both /read and the bsd push read THIS, never the live accumulators -- so the two
// consumers (an external client polls /read in a loop while the push runs every 5s)
// can neither steal each other's samples nor observe a half-swept scan.
static float LastPower[NUM_ports];

// Snapshot every port's average power for the scan that just finished, then clear the
// accumulators for the next scan. The single owner of the reset. A port with no samples
// (shouldn't happen -- every port is swept once per scan) keeps its previous value
// instead of emitting a spurious 0 / nan.
static void harvest_scan() {
  for(uint8_t i = 0; i < NUM_ports; ++i) {
    auto &I = Integral[i];
    if(I.NumSamples > 0)
      LastPower[i] = (I.Power - I.Current * I.Voltage / I.NumSamples) / I.NumSamples;
    I.Power = I.Current = I.Voltage = 0.;
    I.NumSamples = 0;
  }
} // harvest_scan

// Non-destructive: formats the last harvested snapshot for /read and /scan. Safe to poll
// in a tight loop concurrently with the bsd push -- neither touches the live accumulators.
static const String &samples2string() {
  static String s;
  s.reserve(200); // reserve buffer for response to avoid dynamic memory allocation
  s = "";
  for(uint8_t i = 0; i < NUM_ports; ++i) {
    s += String(LastPower[i]);
    s += "<br>";
  }
  return (s);
} // samples2string

// CSV twin of samples2string(): same harvested snapshot, comma-separated. Also
// non-destructive (harvest_scan owns the reset), so the /read poller and this push
// always serialize the same complete set of values.
static const String &samples2csv() {
  static String s;
  s.reserve(200);
  s = "";
  for(uint8_t i = 0; i < NUM_ports; ++i) {
    if(s.length()) s += ",";
    s += String(LastPower[i]);
  }
  return s;
} // samples2csv

// Try hostByName(bare), then hostByName(bare.test), then madpilot mDNS for bare.local.
static IPAddress resolveHost(const char *bare) {
  IPAddress ip;
  if(WiFi.hostByName(bare, ip)) return ip;
  if(WiFi.hostByName((String(bare) + ".test").c_str(), ip)) return ip;
  WiFiUDP udp;
  mDNSResolver::Resolver r(udp);
  ip = r.search((String(bare) + ".local").c_str());
  return (ip != INADDR_NONE) ? ip : IPAddress();
} // resolveHost

// Build the rotating logfile name: PowerMonitor.v<CONF_VERSION>.<MM.YY>.<main|sub>.csv.
// Matches the existing readout_main.py / readout_sub.py output naming. Returns NULL if
// NTP hasn't synced yet (caller should skip the push and try next interval).
static const char *current_logfile_name() {
  static char fname[64];
  time_t now = time(nullptr);
  struct tm *t = localtime(&now);
  if(t->tm_year + 1900 < 2020) return nullptr; // NTP not synced
  const char *type = (VERSION == 1) ? "main" : "sub";
  snprintf(fname, sizeof(fname), "PowerMonitor.v%d.%02d.%02d.%s.csv",
           CONF_VERSION, t->tm_mon + 1, (t->tm_year + 1900) % 100, type);
  return fname;
} // current_logfile_name

void setup() {
  Serial.begin(115200);
  delay(100);
  Serial.println("Serial port connected!");

  SetPins();

  // tell the connection-status blinker which pin to drive (default Blinken in DefaultOpts())
  avp::StaticWiFi_Conn::LED_pin = LED_PIN;

  auto Opts = WebSrv::DefaultOpts();
  Opts.Name = NAME; // NAME should be specified in platformio.ini, so it is in sync with upload_port in espota
  Opts.Version = "5.04"; // /read + push read a per-scan snapshot (no accumulator race); re-resolve bsd; OTA watchdog
  Opts.AddUsage = F("<li><a href='/read'>read</a> - returns column of power value for each port</li>"
                    "<li><a href='/scan'>scan</a> - returns all samples collected so far</li>"
                    "<li> port?i=n - reads port n and returns its value</li>");

  WebSrv::on("/read", []() {
    static String s;
    s.reserve(200); // reserve buffer for response to avoid dynamic memory allocation
    s = "<html>";
    s += samples2string();
    s += "<br></html>";
    WebSrv::send("text/html", s);
    avp::TogglePin<LED_PIN>();
 });
  WebSrv::on("/scan", []() {
    static String Resp;
    Resp.reserve(200);

    Resp = "<html>Scan N: ";
    Resp += NumScans;
    Resp += F("<br>----------------------------------<br>");
    Resp += samples2string();
    Resp += "<br></html>";
    WebSrv::send("text/html", Resp);
   });
  WebSrv::on("/port", []() {
    if(WebSrv::s.hasArg("i")) {
      auto Port = WebSrv::s.arg("i").toInt();
      if(Port < 0 || Port >= NUM_ports) WebSrv::send("text/plain", F("Wrong port number!"));
      else {
        ConnectPort(Port);
        static String Content;
        Content.reserve(80);
        Content = "Port  = ";
        Content += Port;
        Content += ", ";
        Content += analogRead(ANALOG_PIN);

        WebSrv::send("text/plain", Content);
      }
    } else WebSrv::send("text/plain", F("Usage: /port?i=n where n is port number"));
  });

  WebSrv::begin(Opts); // sets up WiFi (state machine), OTA, default handlers, then s.begin()

  // Disable WiFi modem-sleep so the chip reliably receives unicast traffic
  // (the AiMesh node loses unicast packets to sleeping clients).
  WiFi.setSleepMode(WIFI_NONE_SLEEP);

  // NTP -- needed to construct the monthly-rotating filename for the BSD push.
  // configTime is async; loop's push checks time(nullptr) and skips until sync lands.
  configTime(NTP_TZ, "pool.ntp.org");

  // Don't call BSDLog::begin yet -- StaticWiFi_Conn is async, WiFi.localIP isn't
  // valid yet, and we need to resolve "bsd" first. loop() handles it once WiFi
  // is up. RemoteLog::postf is a no-op while URL is unset, so no race.

  debug_puts("Logging here...");
} // setup

void loop() {
  yield();

  // integrating power over one 60Hz wave period
  static avp::TimePeriod1<1000000UL / 60, micros> TP;
  static uint8_t CurPort = 0;
  static uint16_t Counter; ///< we are counting 60 Hz WL periods. During Counter == 0
  // we are reading one port as fast as possible, then we skip WIFI_timeRatio WLs for WiFi to do its thing
  static constexpr uint16_t WIFI_timeRatio = 10; // ratio of WiFi time to analog read time

  if((Counter == 0) && !WebSrv::OTA_IsInProgress) {
    ConnectPort(CurPort);
    uint16_t Current = analogRead(ANALOG_PIN);
    ConnectPort(VoltagePortI);
    uint16_t Voltage = analogRead(ANALOG_PIN);

    Integral[CurPort].Power += Voltage * Current;
    Integral[CurPort].Voltage += Voltage;
    Integral[CurPort].Current += Current;
    Integral[CurPort].NumSamples++;
  } else WebSrv::call_in_loop();
  if(TP.Expired()) {
    if(Counter == 0) {
      if(++CurPort == NUM_ports) {
        CurPort = 0;
        harvest_scan(); // snapshot the finished scan for /read + the bsd push
        ++NumScans;
      }
      Counter = WIFI_timeRatio;
    } else --Counter;
  }

  // Resolve bsd and keep the IP fresh. DHCP can move bsd, and a meter may run
  // for months, so we re-resolve on a cadence (never cache the IP for the whole
  // boot) and re-point the logger whenever the IP changes. A stale cached IP
  // makes every 5s push fail, and the repeated failed connects eventually wedge
  // the heap -- so the device must self-heal when bsd moves.
  static String bsdURL;
  static bool firstTry = true;
  static avp::TimePeriod1<15000, millis> resolveTO; // first try is immediate; then re-check every 15s
  if(WiFi.status() == WL_CONNECTED && (firstTry || resolveTO.Expired())) {
    firstTry = false;
    IPAddress ip = resolveHost("bsd");
    if((uint32_t)ip != 0) {
      String url = "http://" + ip.toString() + ":8000/";
      if(url != bsdURL) { // first resolve, or bsd's IP changed
        bsdURL = url;
        BSDLog::begin(bsdURL.c_str());
        debug_printf("bsd -> %s", bsdURL.c_str());
      }
    }
  }

  // POST a CSV row to bsd every 5 s, matching readout_*.py polling cadence.
  // Skipped while OTA is in progress (no network competition) and while NTP
  // hasn't synced (no valid date to build the filename) and while BSDLog URL
  // hasn't been resolved yet (postf is also a no-op in that case).
  static avp::TimePeriod1<5000, millis> PushTP;
  if(PushTP.Expired() && !WebSrv::OTA_IsInProgress && bsdURL.length() > 0) {
    if(const char *fname = current_logfile_name()) {
      BSDLog::postf(fname, "%s", samples2csv().c_str());
      avp::TogglePin<LED_PIN>(); // visual heartbeat for the push, mirrors /read
    }
  }
} // loop

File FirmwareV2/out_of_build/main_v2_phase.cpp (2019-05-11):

// this file ius different from the main_v2 because it collects phase information
// as well. It does not look like we really need it, phase seems to have about 0.15
// radians error at most which produces < 2% effect
#include <Arduino.h>
#include <EEPROM.h>
#include <ESP8266WiFi.h>
#include <General/Macros.h>
#include <General/Math.h>
#include <stdint.h>
#include <stdio.h>

/////////////////////
// Pin Definitions //
/////////////////////
const uint8_t LED_PIN = D8; // Thing's onboard, green LED
const int ANALOG_PIN = A0;  // The only analog pin on the Thing
constexpr uint8_t NumCtrlLines_74HC4051 = 3;
constexpr uint8_t Num74HC4051 = 2;
static bool RunSampling = true;
constexpr uint32_t WatchDogTime = 1000UL * 60 * 5; // 5 min in ms

static constexpr uint32_t
GetDelay(uint8_t DelIndex) {      // exponentially scaled delay
  return 10UL * pow(2, DelIndex); // us
} // GetDelay

static void (*resetFunc)(void) = 0; // declare reset function at address 0

// WF acronim is WaveForm, one 60 Hz period
static constexpr uint16_t SAMPLES_IN_WF = 600;
static constexpr uint32_t WF_SAMPLE_PERIOD =
    1000000UL / SAMPLES_IN_WF; // microseconds

static uint32_t Delay =
    GetDelay(4); // tuned for no visible phase shift. Hmm, HOW?
static uint32_t NewSample = micros();
static inline void Set74HC4051_code(uint8_t c, uint8_t SwitchNum);

#if VERSION == 2
#include "V2.incl"
#else
#include "V1.incl"
#endif

constexpr uint8_t VoltagePortI = 0;
constexpr uint8_t GND_PortI = NUM_ports - 1;

static inline void Set74HC4051_code(uint8_t c, uint8_t SwitchNum) {
  for (uint8_t BitI = 0; BitI < NumCtrlLines_74HC4051; BitI++)
    digitalWrite(ControlLines[SwitchNum][BitI], (c >> BitI) & 1);
} // Set74HC4051_code

static inline bool is_past_us(uint32_t time_us) {
  return (micros() - time_us) < (1UL << 31);
} // is_past

static inline bool is_past_ms(uint32_t time_ms) {
  return (millis() - time_ms) < (1UL << 31);
} // is_past

// integration data
static struct {
  float PowerRe, PowerIm, Voltage, VoltageQourter, Current;
  uint32_t NumSamples;
} Integral[NUM_ports];

static uint32_t NumScans;

/**
samples samples over one 60 Hz Wave alternatively from CurPort
port and from VoltagePort and then accumulates them into PowerRe[CurPort] and
NumSamples[NUM_ports] and moves CurPort to the next port

NEW: it looks like we do need phase information, as our Voltage signal seems to
have very significant phase shift, which screwes our measurement badly. So, to
get an imaginary part, we got to start collecting Voltage samples a quater
wavelength
in advance, and do multiplication by cotimed samples and shifted by 1/4 WL
*/
static inline void sample_port_and_go_to_next() {
  static uint8_t CurPort = 0;
  static uint16_t BufferSize = 20; // just some initial size
  static uint16_t *pVoltageBuffer =
      new uint16_t[BufferSize]; // lets make autogrowing buffer
  uint16_t VoltageSampleI = 0;
  uint16_t VoltageIquorterShift = 0;

  uint32_t QuorterUntil =
      micros() + 1000000UL / 60 / 4; // that's when 1/4 WL presampling stops
  uint32_t SampleUntil =
      QuorterUntil + 1000000UL / 60; // and them we sample for another WL

  ConnectPort(VoltagePortI);
  uint16_t Voltage = analogRead(ANALOG_PIN); // to avoid phase shift we will
  // average voltage betweenn two consequitive samples, to bring time to
  // the same moment I sample current
  while (SampleUntil - micros() < (uint32_t(0) - 1) / 2) {
    if (VoltageSampleI == BufferSize) { // oops, got to grow the buffer
      uint16_t *pOldBuffer = pVoltageBuffer;
      pVoltageBuffer = new uint16_t[BufferSize *= 2];
      memcpy(pVoltageBuffer, pOldBuffer,
             BufferSize); // means BufferSize/2*sizeof(uint16_t)
      delete[] pOldBuffer;
    }

    ConnectPort(CurPort);
    uint32_t Current = analogRead(
        ANALOG_PIN); // it is 32-bit to avoid overflow on multiplication
    ConnectPort(VoltagePortI);
    uint16_t NewVoltage = analogRead(ANALOG_PIN);
    Voltage = (Voltage + NewVoltage) / 2;
    pVoltageBuffer[VoltageSampleI++] = Voltage;

    if (QuorterUntil - micros() < (uint32_t(0) - 1) / 2) {
      // We are precollecting voltage samples. To keep the period we have to do
      // the same calculations
      volatile float Idle;
      Idle += Voltage;
      Idle += Voltage * Current;
      Idle += pVoltageBuffer[VoltageSampleI - VoltageIquorterShift];
      Idle += pVoltageBuffer[VoltageSampleI - VoltageIquorterShift] * Current;

      Idle += Current;
    } else {
      if (VoltageIquorterShift == 0)
        VoltageIquorterShift = VoltageSampleI;
      Integral[CurPort].Voltage += Voltage;
      Integral[CurPort].PowerRe += Voltage * Current;
      // Next is voltage shift by 1/4 WL
      Integral[CurPort].VoltageQourter +=
          pVoltageBuffer[VoltageSampleI - VoltageIquorterShift];
      Integral[CurPort].PowerIm +=
          pVoltageBuffer[VoltageSampleI - VoltageIquorterShift] * Current;
      Integral[CurPort].Current += Current;
      Integral[CurPort].NumSamples++;
    }
    // yield();
    Voltage = NewVoltage;
  }
  if (++CurPort == NUM_ports) {
    CurPort = 0;
    ++NumScans;
  }
} // sample_port_and_go_to_next

WiFiServer server(80);

void setupWiFi() {
  WiFi.mode(WIFI_AP);

  // Do a little work to get a unique-ish name. Append the
  // last two bytes of the MAC (HEX'd) to "Thing-":
  uint8_t mac[WL_MAC_ADDR_LENGTH];
  WiFi.softAPmacAddress(mac);
  String macID = String(mac[WL_MAC_ADDR_LENGTH - 2], HEX) +
                 String(mac[WL_MAC_ADDR_LENGTH - 1], HEX);
  macID.toUpperCase();
  String AP_NameString = "ElPanelV2 " + macID;

  char AP_NameChar[AP_NameString.length() + 1];
  memset(AP_NameChar, 0, AP_NameString.length() + 1);

  for (uint8_t i = 0; i < AP_NameString.length(); i++)
    AP_NameChar[i] = AP_NameString.charAt(i);

  WiFi.softAP(AP_NameChar, WiFiAPPSK);
}
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

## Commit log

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2018-01-02 Is loop spinning too slow? Will sample voltage and current at the same time next
2018-01-04 Created altium files
    [PCB_Project.PrjPcb]
2018-01-06 Send PCB for production
    [PCB1.PcbDoc, PCB_Project.PrjPcb, Sheet1.SCHLIB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]
2018-01-29 Fixing mistakes
    [PCB1.PcbDoc, PCB1a.PcbDoc, PCB_Project_A.PrjPcb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]
2018-02-03 Will change sampling sequence, because currently 60 Hz is sampled at 30 Hz
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2018-10-06 Updated panels drawing to proper numbering
    [2018-02-20T10_53_02.csv, PCB1_1.PcbDoc, PCB_Project1.PrjPcb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]
2018-11-10 New version with both connectors
    [PCB1a.PcbDoc, PCB_Project1.PrjPcb, PCB_Project_A.PrjPcb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]
2018-12-04 Before doing firmware for v2.
    [Old_summary.xls, PCB1_1.PcbDoc, PCB1a.PcbDoc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]
2018-12-06 Communication is OK, we will fix calculations next
    [main_v2.cpp]
2019-01-05 Basically done, only cover left
    [Old_summary.xls, PCB1a.DWG, PCB1a.DXF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]
2019-05-11 Ok, phase works find, but we do not need it, so reverted back. Circuit diagram is corrected, and lower power consumption circuits are moved to higher power.
    [main_v2_phase.cpp]
2020-01-02 Implemented month_by_month and included all missing files...
    [Part1.DXF, Part1.STEP, Part2.DXF]
2025-07-02 Compiles, loads, but as soon as I start using ADC WiFi dies. Tried to use ADC less often, did not help. Let's try using ASYNC server.
    [Old_summary.xls]
2025-07-03 It seems that a lot of time is wasted on String reallocations. Lets fix that.
    [main_v2.cpp]
2025-07-04 Something is wrong with data collection.
    [main_v2.cpp]
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2026-05-25 Update EPM FirmwareV2 + delete legacy Firmware/ AVR tree
    Submodules bumped to truly-latest tips (matching other ESP8266 projects):
    C_ESP PLUG: c11c717 -> e8f6543 (RemoteLog, fast_wake, Crc32 use)
    C_General Senzime: 2ba0c1a -> 98a8792 (Crc32 added)
    platformio.ini:
    - Add build_unflags = -std=gnu++11 (canonical pair with gnu++17)
    - Add monitor_dtr = 0 / monitor_rts = 0 -- without these pio device
    monitor toggles RST on the nodemcu reset circuit and the chip
    looks like it's in a bootloop. Bit us hard in CaliperOnESP03.
    main_v2.cpp: Opts.Version 3.01 -> 3.02 (the only place this is
    displayed -- on the StaticWebServer root page).
    CLAUDE.md: drop the stale "mid-rename" not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
    [esp8266.h, main_v2.cpp]
2026-05-25 Bump C_ESP: pick up StaticWiFi_Conn router-reset mDNS recovery fix
    C_ESP PLUG: e8f6543 -> 5dc53bd
    Fixes the symptom user reported: device registers in mDNS fine but
    vanishes from avahi-browse / Bonjour after a router reset, with
    connectivity by IP still working. ConfirmConnected now waits for
    DHCP to finish before transitioning to CONNECTED + calling
    MDNS.notifyAPChange().
2026-05-25 EPM main page: wrap /read and /scan in <a href=...> links; v3.03
    Per the global "AddUsage links" rule: any endpoint that responds
    usefully to a bare GET gets wrapped in <a href='/...'>. /port?i=n
    stays plain text since it requires a parameter.
    I'd missed auditing AddUsage when bumping v3.02 -- caught by user.
    Saving a reminder so I check it on every visit to a project that
    uses StaticWebServer.
    (Also picks up the user's netname change to EPM_main and -DVERSION=1
    in platformio.ini.)
    [main_v2.cpp]
2026-05-26 EPM v4.00: push CSV to bsd/http_server every 5s; split into main/sub envs
    main_v2.cpp:
    - NTP via configTime (EST5EDT default; override with -DNTP_TZ=...). Needed
    to construct the monthly-rotating filename for the push.
    - 5 s push timer in loop() that POSTs to bsd via avp::RemoteLog::postf.
    Skipped during OTA and while NTP hasn't synced.
    - samples2csv_and_reset(): twin of samples2string() but comma-separated.
    Both reset accumulators; during the cutover window /read polling and
    push race -- whichever fires first gets the interval. After power_monitor
    is retired on bsd, push owns the data path cleanly.
    - current_logfile_name() builds "PowerMonitor.v<CONF_VERSION>.<MM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
    [main_v2.cpp]
2026-05-26 EPM v4.02: bump C_ESP for HTTP_POST_puts fix (setReuse + dangling pointer)
    C_ESP PLUG: fc916a2 -> 4680d7a. Fixes the "every push returns -1
    after the first" pattern by dropping setReuse(true) -- Python
    http.server closes the connection after each response, so reuse was
    always doomed. Also fixes the garbled error string (was using a
    dangling .c_str() into a destroyed temporary).
    Opts.Version 4.01 -> 4.02.
    [main_v2.cpp]
2026-05-26 EPM v4.04: pre-resolve bsd via caliper-style chain; log dedup; resolve diag
    - Add mDNSResolver dep + resolveHost() chain copied from caliper:
    hostByName("bsd") -> hostByName("bsd.test") -> mDNS "bsd.local".
    Runs from loop() after WiFi up; caches the resolved IP into a
    URL string and feeds that to BSDLog::begin(). HTTPClient was
    seeing HTTPC_ERROR_CONNECTION_FAILED on every push because
    "bsd" alone wasn't resolving via its internal DNS path; pre-
    resolving to an IP-URL sidesteps that.
    - debug_puts now calls HTML_Log::Add(s, true) so /log gets <br>
    between entries (was running together as one long line).
    - Diag log on resolve attempt + failure (th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
    [main_v2.cpp]
2026-05-26 EPM v4.06: remove hostByName retry layer
    Experimental retry-with-200ms-gap layer ran -- all 3 attempts failed
    in a row, so retries don't help on this LAN. Removed per "no defensive
    code just in case." resolveHost falls through to mDNS exactly as
    caliper has been doing all along (caliper's DNS attempts also silently
    fall through; mDNS does the actual work).
    Working hypothesis for why hostByName fails for bsd / bsd.test on
    this LAN: dnsmasq's local-name answers carry TTL=0 (confirmed via
    `drill @192.168.50.1 bsd.test` from bsd) and arduino-esp8266's lwIP
    treats TTL=0 as no-answer. wttr.in worked historically because
    forwarded responses carry the upstream TTL. To be verified by adding
    local-tt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
    [main_v2.cpp]
2026-05-26 EPM v4.07: toggle green LED on every push (visual heartbeat)
    Mirrors the LED behavior of /read -- avp::TogglePin<LED_PIN>() after
    each successful BSDLog::postf. With 5 s push interval, the LED toggles
    twice per 10 s, giving an at-a-glance "is the device still pushing"
    indication without needing to check the server.
2026-05-26 EPM v4.08: per-variant LED_PIN; V1 uses D0 (red LED on old NodeMCU)
    Hardcoded LED_PIN to D8 didn't match EPM_main's hardware (oldest
    NodeMCU variant has its onboard red LED on GPIO16 = D0). Make it
    conditional on VERSION:
    V1 (main): D0 -- red onboard LED
    V2 (sub): D8 -- external green LED, unchanged
    Blinken (status indication) and push-heartbeat both use LED_PIN, so
    both now drive the right LED per board class.
    [main_v2.cpp]
2026-05-27 Revert "EPM v4.08: per-variant LED_PIN; V1 uses D0 (red LED on old NodeMCU)"
    This reverts commit baba906e94dee345e5bc01bed81d8ba95c78f034.
    [main_v2.cpp]
2026-05-27 EPM v5.00: trim verbose debug; resolveHost succeeds first-try via hostByName (DNSFilter mode=1 now sends local-name queries to dnsmasq)
    [main_v2.cpp]
2026-05-29 Bump C_ESP to master (HTTP_POST 1s timeout, mDNS-recovery fix); EPM v5.01
    The synchronous BSD POST blocked the main loop on a stalled connection,
    starving the ADC sampler so the next 5s interval logged all zeros. The
    C_ESP bump cuts the POST timeout 5s->1s (bounds the stall) and also brings
    the StaticWiFi_Conn mDNS-recovery fix.
    [main_v2.cpp]
2026-06-08 EPM v5.02: re-resolve bsd on a cadence (no stale cached IP); /read zero-guard
    The push target was resolved once at boot and cached for the whole run, so when
    bsd's DHCP IP changed every 5s POST went to a dead address forever -- and the
    repeated failed connects fragment/exhaust the heap until the device wedges. Now
    loop() re-resolves "bsd" every 15s and re-points RemoteLog whenever the IP
    changes, so a meter self-heals when bsd moves (main already recovered by virtue
    of a router-reboot-forced reconnect; sub, up continuously, never did).
    Also guard samples2string() against NumSamples==0: a /read landing right after a
    push reset divided 0/0 and printed "nan" for every port; emit 0 instead, mat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
    [main_v2.cpp]
2026-06-08 EPM v5.03: pull C_ESP OTA-stall watchdog; version bump
    Bump C_ESP to the ElectricPanelMeter branch tip carrying the OTA-stall watchdog,
    so a wedged OTA (which froze sub's sampling and logging for ~20h) now self-recovers
    by reboot instead of needing a manual power-cycle. Both envs compile clean.
    [main_v2.cpp]
2026-06-08 EPM v5.04: /read + push read a per-scan snapshot (kill the accumulator race)
    /read is polled in a loop by an external client at the same time as the 5s bsd
    push, and both used to compute-and-RESET the shared per-port accumulators. They
    stole each other's samples, so a concurrent /read returned a half-swept scan --
    ports not yet re-sampled since the last reset showed nan (or 0 with the v5.02
    guard). Real powered channels never read 0, so those were pure artifacts.
    Decouple sampling from reading: harvest_scan() snapshots every port's average
    power once per finished scan into LastPower[] and is the sole owner of the reset.
    samples2string() (/read, /scan) and samples2csv() (push) are now pure r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
    [main_v2.cpp]
2026-06-08 MATLAB read_file: DST-aware local time (fixed -5 was 1h off all EDT half-year)
    Convert the epoch column via the America/New_York zone (auto EST/EDT) then drop
    the zone to a naive datenum, instead of a hardcoded -5. kWh/price/gap detection
    were already TZ-invariant (they use differences); this fixes the 1h x-axis label
    shift during the Mar-Nov EDT window. Verified against May 2026 sub data.
2026-06-26 Open-project housekeeping: bump shared libs, drop dead files
    - Bump submodules to current development tips (compiles clean, both
    envs: main Flash 38.7% / RAM 44.9%, sub SUCCESS):
    C_General 192ba36 -> 277e8fd (svprintf_puts, get_be16/32, 64-bit fixes)
    C_ESP 95d25e2 -> a656e17
    MATLAB/AVP_LIB gitlink -> 532b558
    - Remove obsolete host-side polling scripts readout_main.py / readout_sub.py:
    since firmware v4.00 the device pushes the same CSV rows to bsd directly.
    - Remove dead files: .travis.yml (fully commented-out CI, also gitignored),
    2018-02-20T10_53_02.csv (stray sample), FirmwareV2/adc.c + adc1.c
    (uncompiled vendor ADC scratch, not under src/).
    - README: note logging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
    [2018-02-20T10_53_02.csv]
2026-06-26 read_file.m: fix epoch-only files; split formats by '-' not datetime/NaT
    datetime(...,'InputFormat',...) throws (not NaT) when NO element matches, so
    the previous isnat()-based split errored on any all-epoch (pre-2026-06-23)
    file. Discriminate by structure instead: the human-readable timestamp
    contains '-' (date separators), legacy epoch floats don't. Parse each group
    its own way and only call datetime() on the human-readable subset.
    Verified on the live dual-format file /mnt/T/PowerMonitor.v0.06.26.main.csv
    (42533 rows, epoch through 2026-06-23 23:18 then human-readable to date):
    plots continuously across the format boundary with no discontinuity.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
2026-06-26 show1.m: read the live log dir, not the stale ARCHIVE copy
    //bsd/ARCHIVE/POWER (=/POOL/ARCHIVE/POWER) stopped updating Jun 1; the
    device's http_server.py push writes to bsd /mnt/T, exported over SMB as
    //bsd/USB_FLASH. Point show1 there so current-month plots show live data.
    Verified: show1(false,6,26) reads and plots the live 06.26 main file.
2026-06-26 show1.m: read archived monthly logs from //bsd/ARCHIVE/POWER
    The device pushes live rows to bsd /mnt/T (SMB //bsd/USB_FLASH); a monthly
    job moves each finished month's file into /POOL/ARCHIVE/POWER. show1 plots
    finished months, so it reads the archive. Documented the data flow inline so
    the path is not repointed at the live buffer again.
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2026-09-03 Point conf.dir at the ESP log sink's new home on bsd
    conf.dir was 'R:\ARCHIVE\POWER\', which never resolved: R: maps to
    \\bsd\Packages (/POOL/Packages), not to ARCHIVE, so the path was
    \\bsd\Packages\ARCHIVE\POWER\ and did not exist.
    bsd's http_server CSV sink moved from the /mnt/T USB pen drive to
    /POOL/ARCHIVE/ESP_LOGS on 2026-09-02 (the old ARCHIVE/POWER directory
    was renamed at the same time). The [ARCHIVE] Samba share maps
    /POOL/ARCHIVE, so the correct path is \\bsd\ARCHIVE\ESP_LOGS\ -- and
    unlike the old value it now reaches LIVE data, not a monthly snapshot.
    read_file.m is unaffected: it takes the filename as an argument and
    hardcodes no path.
    Edited byte-preserving; this file uses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
2026-09-03 Point the MATLAB scripts at the ESP log sink's new home
    show1.m and month_by_month.m both hardcoded the old archive location and
    neither was caught when conf.dir was fixed in 21301ca -- conf.dir is read
    by nothing, so that commit alone left these scripts broken.
    show1.m cd('//bsd/ARCHIVE/POWER/') -> //bsd/ARCHIVE/ESP_LOGS/
    month_by_month.m cd('R:\ARCHIVE\POWER') -> //bsd/ARCHIVE/ESP_LOGS/
    conf_sub_v2.m conf.dir -> //bsd/ARCHIVE/ESP_LOGS/
    R: maps to \\bsd\packages, not to ARCHIVE, so month_by_month.m's path had
    never resolved at all.
    Forward-slash UNC throughout, matching the idiom show1.m already used.
    Measured on R2024b: MATLAB accepts both //bs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
2026-09-04 Correct the log-sink path in the notes; record the rotation truncation
    FirmwareV2/CLAUDE.md still named /mnt/T as the push destination. The sink moved
    to /POOL/ARCHIVE/ESP_LOGS on 2026-09-02, and /mnt/T is still mounted and still
    answers reads with pre-move data and no error -- so a stale note there sends a
    reader to plausible wrong rows rather than to a failure.
    While verifying the live sink for a HOUSE_POWER interface question, found that
    http_server.py rotates past 10 MiB into a single .1 that it overwrites. At the
    meters' 104 KB/h that fires every ~4 days, so every month since 2026-06 retains
    only its last few days; June-August 2026 is unrecoverable. Recorded as project
    memory and repor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
2026-09-04 Memory: months merged, pre-merge store outside the sink dir, fix staged on bsd
2026-09-04 Grounding-strip finding: intermittent by day, matching no metered circuit
    Corrects the earlier note. HOUSE_POWER's paired-difference test kills the
    crosstalk hypothesis I had raised -- against 106 compressor steps >50 W the
    feeders respond at slope 0.31-0.35 while Grounding strip gives 0.0037, r=0.023,
    and the subtracted GND reference does not move with load either. So there is no
    load-scaling floor on the small channels, and the two dead channels are dead.
    Reproduced the real shape here: daily medians alternate 4.6-13.5 W against
    71-114 W, ratio 10.2x, p95 to 920 W, onset between 2026-08-01 and 08-25. No
    metered channel tracks it -- best is Main Black at r=0.48, and the A/C is
    anti-correla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
2026-09-04 scripts: add port10_history.py for dating a channel's failure
    Monthly medians across the whole archive, with the raw covariance value beside
    the GND reference so a channel reading below the reference (hence a floored 0 W)
    is distinguishable from one reading a genuine small signal.
2026-09-04 Air handler channel: never read right, and fully dead since 2024-10
    Dating the channel across the whole archive changes the diagnosis. Port 10 read
    3-20 W from 2018-12 to 2024-09 -- far too little for a blower that runs
    continuously, so it was mismeasuring from the first month, consistent with a CT
    around a whole cable where go and return cancel. Then in 2024-10 the raw
    covariance stepped from ~360 to 201 against a ~308 reference and has sat below
    the reference since, which floors the watts at zero. Two faults, and fixing only
    the second one buys back 8-20 W rather than the real load.
    40 Lida read 15-91 W until 2021-08 and exactly 0.0 since 2021-10; the user says
    that circuit is barely used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
2026-09-04 Retract the scale-drift finding; labels in conf_main_v0.m are unreliable
    Two corrections from the user, both of which kill inferences I had recorded.
    22 heat exchanger is not a constant load: he ran it through an auto-transformer
    and adjusted it periodically, removing the transformer during 2026. Its
    122 -> 79 -> 119 -> 107 W history is those adjustments, so it cannot calibrate
    anything and must not be used to normalise across years. With no validated
    constant load in the data, gain stability across firmware epochs is unmeasured in
    both directions. What survives is narrower: the GND reference steps ~300 -> ~550
    at the 2025-12 rebuild, and since it is subtracted from every channel it pushes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
2026-09-04 A flat 0.0 W is the GND subtraction flooring, not a disconnected CT
    read_file.m computes max(|col|-|gnd|,0), so any channel below the noise reference
    reports exactly zero. In 2024-10 four main channels read 0.0 every day, including
    the A/C compressor in a month with no cooling -- so a zero is "below the
    reference", and only a step in the RAW value against a stable reference shows a
    physical change. Port 10 does show one (351 -> 201 between 2024-09 and -10 while
    the reference moved 324 -> 308), so that event stands; the general inference from
    zeros does not.
    Dating it also puts a September 2024 step on main within weeks of an independently
    detected 2024-10-17 epoch boundary on sub, with no f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
2026-09-04 Record the ground-current causes, with the citations actually checked
    Research offloaded to the local model, then verified here rather than relayed:
    Mike Holt's E=I*R worked example (1.25 V) and EC&M's load-side green-bonding-screw
    case both check out and are quoted correctly, and the NEC numbering 250.142(B)
    "Load-Side Equipment" and 250.6 "Objectionable Current" was confirmed from
    independent sources. Two citations did not survive: the IAEI parallel-paths
    article returns 403 from here, so its quote is unverified, and NEC section TEXT
    was cited only to a third-party HuggingFace scrape of NFPA-copyright material,
    which is no authority at all.
    The Y-capacitor exclusion is arithmetic anyone c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
2026-09-04 Memory: the diverted SHARE is the monitor, and the CT is back on the GEC
    Replaces the power-factor note, which compared today's watts to the clamp reading
    without checking whether the CT was still on that conductor. It is -- but only
    since 2026-08. Per-month regression of port 9 on the service-neutral unbalance
    gives 0.31 (2022-06) and 0.30 (2023-06), collapsing to ~0 by 2026-02 and returning
    at 0.187 and 0.360 in 2026-08 and -09.
    That makes the share, not the watts, the quantity to track: it is the ratio of two
    numbers off the same board, so the board coefficient cancels and it is the one
    figure comparable across firmware epochs -- and a rising share is precisely the
    service-neutral degrad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
2026-09-04 Port 9's CT is on a different wire, not loose on the GEC
    The user suspects he moved it and forgot, and the levels settle it. A loose CT
    scales the same waveform, so at a coupling ratio of 0.034/0.319 port 9 should read
    125.1 * 0.107 = 13.3 W; it actually reads 64.8 W (2026-08) and 84.4 W (2026-09),
    4.8-4.9x more than the GEC can account for. The excess is a second source, which a
    scaling argument cannot produce -- so it is another conductor.
    Two consequences. The GEC is currently unmonitored, so the fix is to move the CT
    back rather than re-tighten it. And the three-state "appliance" signature
    HOUSE_POWER characterised in 2026-08/09 -- a flat ~87 W plateau for 8+ hours with
    500-1000 W burst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
2026-09-04 Record the rectified-floor defect; refresh the notes that went stale today
    read_file.m takes abs() per row and averages afterwards, and mean(|x|) is not
    |mean(x)|. Each CSV value is a single-cycle covariance from one free-running
    ~16.67 ms window, so it scatters widely, and rectifying that scatter produces a
    positive constant wherever the true term is small -- measured by HOUSE_POWER
    against 26 utility bills as a ~2.1 kW floor on the feeder channels, which do not
    move at all while the bill swings 6.7x. The sign survives on the wire (no abs()
    anywhere in main_v2.cpp), so it is fixable host-side, and fixing it also restores
    direction of flow.
    Also refreshes two notes overtaken by events: the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
2026-09-04 Subtract the GND reference signed, not from the magnitude
    Every CSV value is a signed cov(V,I) over one free-running 60 Hz window, and the
    last column is a grounded mux input carrying the additive offset common to every
    channel. The readers all computed max(|col| - |gnd|, 0) per row, which subtracts
    that offset from the MAGNITUDE. On a channel whose CT is reversed -- Subpanel Red,
    Main Black, 26 -- that is the wrong sign, understating it by 2*gnd: ~1012 counts,
    ~140 W. Main Black is a feeder, so the mains total was low by that much: 2533 ->
    2675 W on 2026-09, +5.6%. The error scales with gnd, so it nearly doubles across
    the 2025-12 firmware step (~85 W before, ~140 W after) and is epoch-depe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
2026-09-04 Publish the per-month GND-sign correction table
    HOUSE_POWER calibrated its bill fit on uncorrected mains, so it needs to correct
    published figures rather than re-derive them. One row per month, 2018-12..2026-09,
    old and new watts for both feeders and the Grounding strip.
    The measured epoch step is in it: mains correction is +3.2 to +5.0% in every month
    through 2025-06, then +4.7 to +7.2% from 2025-12 on, which is the GND channel's
    ~300 -> ~550 count step at that firmware rebuild appearing exactly where it must.
    ~82 W before, ~150 W after.
    Also records what the fix does to port 9: its pre-2024 levels were largely
    rectification artefact (2019-02 reported 103.8 W, actually 4.0), so it was
    int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
    [gnd_sign_correction_by_month.csv]
2026-09-04 Record the scale-epoch history; close the GEC question
    HOUSE_POWER was inferring calibration epochs from the signal and both of its
    detectors were unstable on main. The repo already holds the answer, so it is
    written down: every conf edit, every firmware change that can move the scale, and
    the two structural facts that remove whole classes of false boundary -- a conf edit
    rescales a version's history retroactively and can never step the data at its edit
    date, and the boundary is the per-board FLASH date, not the commit date (main took
    the 2025-07-03 sampling rewrite only at its 2025-12-10 flash).
    The GND column turns out to be the epoch instrument: it carries no load, and it is
    flat within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
2026-09-04 A channel reading nothing becomes the GND column, and fakes a coupling
    HOUSE_POWER found that my 2024-10/11 "one leg" result was an artefact, and it
    reproduces in raw signed counts where no sign convention can reach: r(dp9, dgnd) is
    ~0 for every month 2018-12..2024-09, then 0.890, 0.931 and 0.984-0.996 across
    2024-10..2025-06. In that window port 9 IS the reference -- the CT reads nothing,
    p9-gnd is ~0, and any statistic on it correlates with every channel through the
    shared gnd term. Because a reversed CT's watts carry +gnd and a normal one's carry
    -gnd, that always looks like "black high, red low", which is exactly the branch
    signature I read off it.
    So the branch move is bounded, not dat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
